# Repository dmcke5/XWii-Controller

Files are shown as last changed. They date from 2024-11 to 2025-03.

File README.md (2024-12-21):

# XWii Controller
An Xbox One style controller with a Wii U layout!

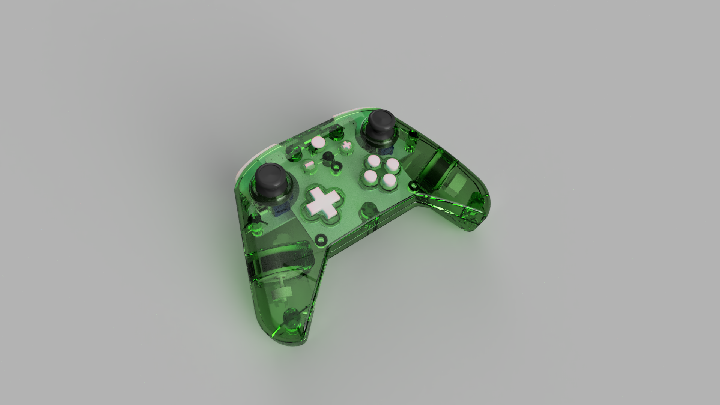
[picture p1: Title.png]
Xii-U Controller


The Wii U gamepad layout is a fan-favourite for many gamers yet it is rarely used in the current generation of controllers. This open source project brings the Wii-U layout back but in a shape more akin to an Xbox controller and provides you with a cool piece of tech that you can be proud to say you built yourself!

Features:
- Wii-U controller layout
- Hall Effect Joysticks
- Hall Effect Triggers
- Rumble
- Xinput Compatible
- RGB Status indicator home button

For now, this controller is wired only but I plan to add a wireless version of the design at some point in the future!

# Print Orientation

If you're printing the housing at home on an FDM printer here's some tips to get the best finish possible!

#### Front Housing

Stand the front housing on its top edge and lean it forward 45 degrees. Enable supports for surfaces over 55 degrees and use a raft to ensure good adhesion to the bed. Ensure Z seam is on the inside! Only minimal supports should be generated, just to support the bottom of the button holes. If you're using a bed-slinger, orient your part so that it runs with the direction your bed moves to reduce wobble.

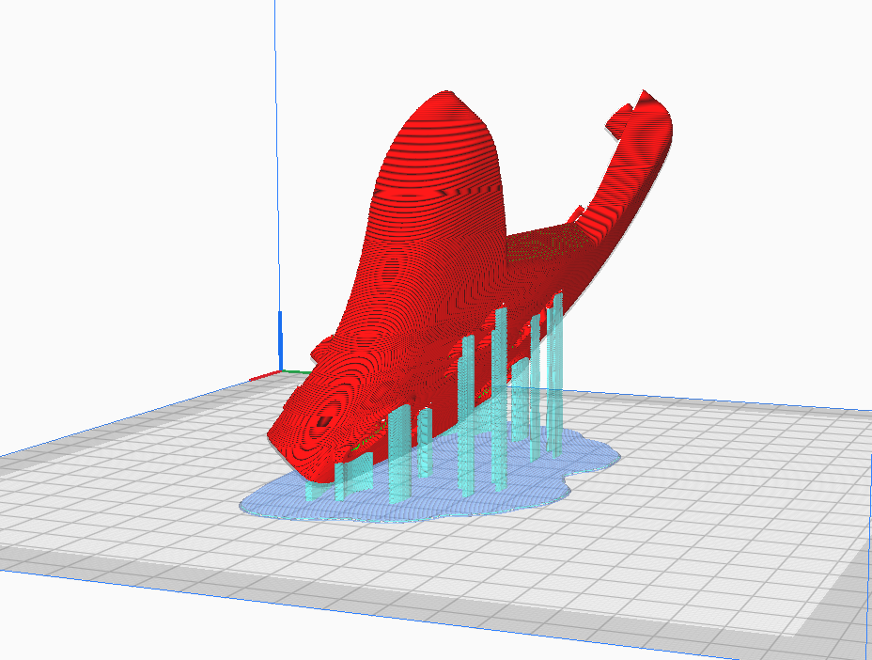
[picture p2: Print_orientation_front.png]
Print orientation front


#### Rear Housing

Stand the rear housing on its top edge and lean it back 30 degrees. Enable supports for surfaces over 55 degrees and use a raft to ensure good adhesion to the bed. Ensure Z seam is on the inside! Some supports will be generated on the inside but none are in contact with critical surfaces making cleanup relatively easy. Same as the front, ensure orientation matches your bed movements for bed slinger printers!

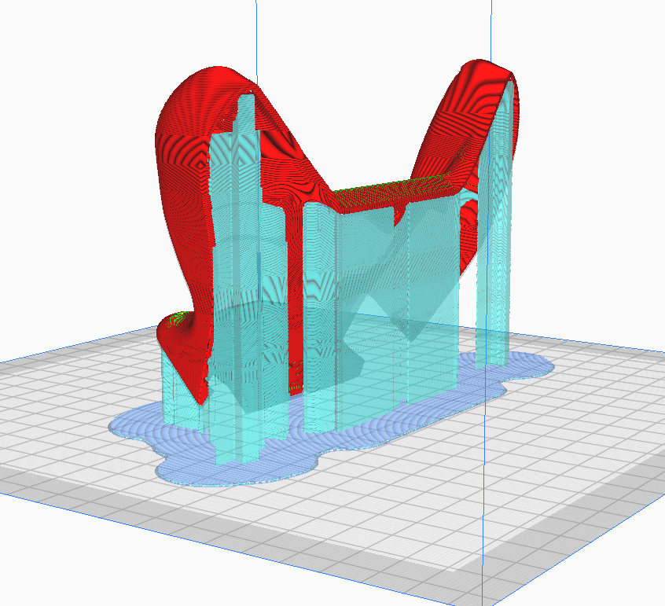
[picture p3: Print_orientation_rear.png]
Print orientation rear


#### Shoulder Buttons

Shoulder buttons should be printed flat on the bed, to ensure the spring is working with the layers rather than against them. Enable supports so the top edge of the buttons aren't left hanging.

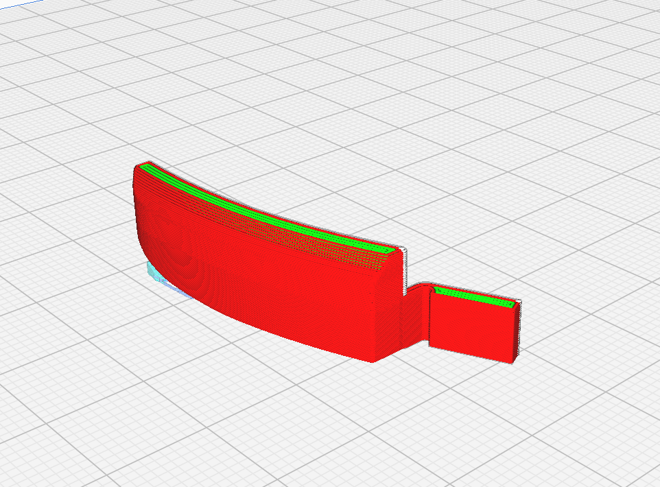
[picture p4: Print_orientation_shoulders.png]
Print orientation shoulders


#### Trigger Buttons

Stand trigger buttons on their end and rotate forward 30 degrees. Enable supports for surfaces over 55 degrees and enable raft. Supports should be generated in the holes and for the magnet mount only leaving very little cleanup required.

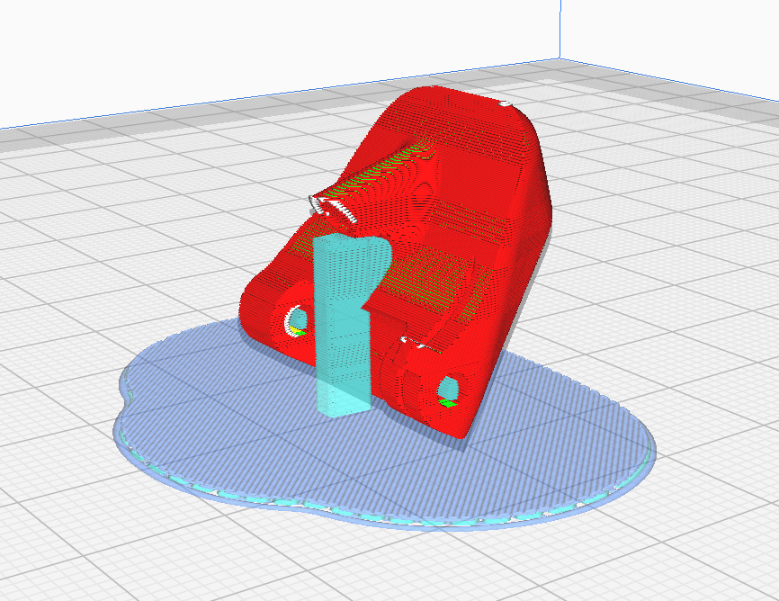
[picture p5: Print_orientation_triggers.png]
Print orientation triggers


# Bill of materials

#### PCB's

1x Front PCB (Must use ENIG finish!)

1x Rear PCB

#### 3D Printing

1x Controller Housing Top

1x Controller Housing Bottom

1x LHS Shoulder Button

1x LHS Trigger

1x RHS Shoulder Button

1x RHS Trigger

#### Purchase

1x Switch lite button set - https://www.aliexpress.com/item/1005007266706005.html

1x Switch lite membrane set - https://www.aliexpress.com/item/1005004544710872.html

2x PS5 Hall sensor joysticks - https://www.aliexpress.com/item/1005007688806322.html

1x Xbox rumble motor (pair) - https://www.aliexpress.com/item/1005002877455453.html

2x PS4/5 Trigger Springs - https://www.aliexpress.com/item/1005005844578554.html

2x 3x1mm Neodymium Magnets - https://www.aliexpress.com/item/1005006619263188.html

1x 6028 RGB LED - https://www.aliexpress.com/item/1005003719602946.html

1x WS2811 IC - https://www.aliexpress.com/item/32844615804.html

1x USB Data Cable (End will be removed so only need to ensure it has the correct end for your device on one end of the cable)

#### Hardware

5x M3x5x5 Threaded Inserts

2x M2x3.2x3 Threaded Inserts

3x M2x3.2x4 Threaded Inserts

5x M3x8 SHCS Screws

6x M2x4 SHCS Screws

# PCB Assembly

#### Front PCB:

Follow the diagram below for locations of components. Pay close attention to orientation of parts U1, Y1, U7 and D1 as they can be fitted in the wrong direction and cause damage. Align marks on all these components with the alignment marks on the PCB.

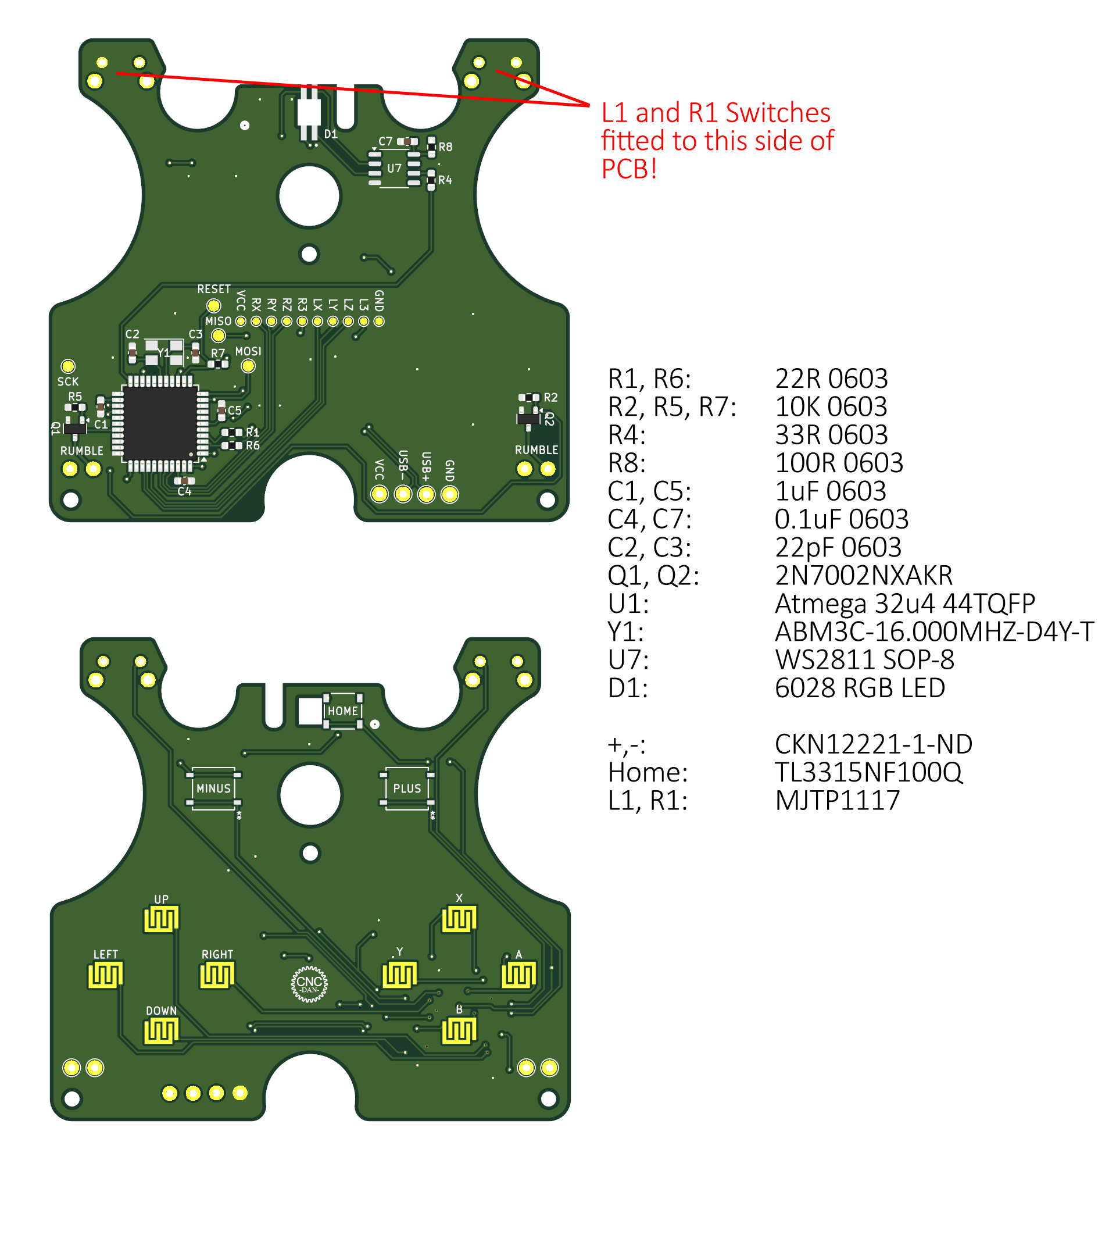
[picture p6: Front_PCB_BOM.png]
Front PCB BOM


#### Rear PCB:

Follow the diagram below for locations of components. Fit joysticks to opposite side of PCB.

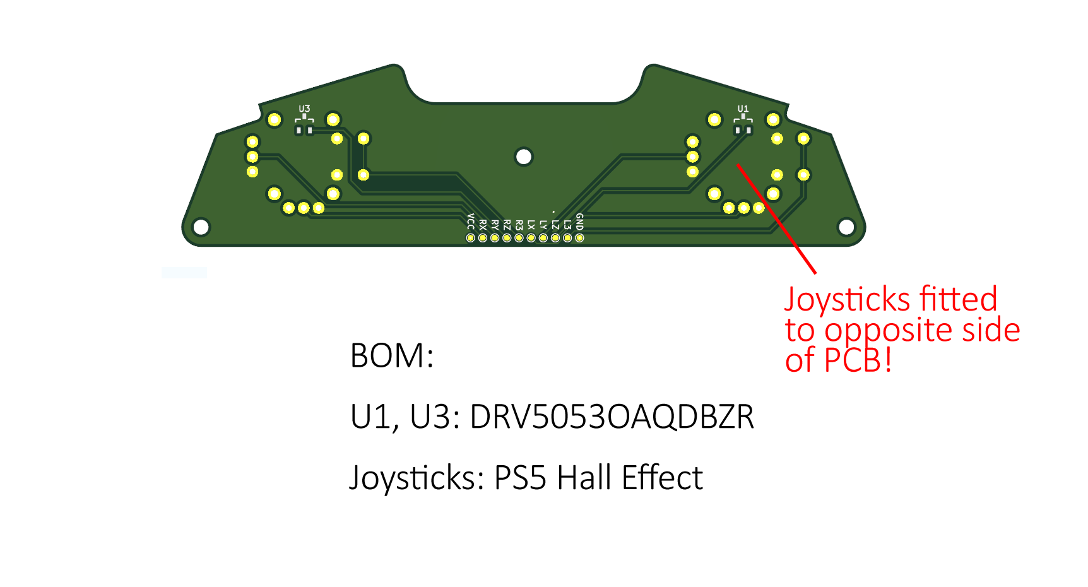
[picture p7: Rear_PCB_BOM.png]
Rear PCB BOM


# Software

You will need to install these libraries to be able to compile the code:

XInput: https://github.com/dmadison/ArduinoXInput

FastLED: https://github.com/FastLED/FastLED

Then simply compile and upload to your controller using the Leonardo w/xinput board option. Please note, once the code is uploaded you will need to re-flash the bootloader to be able to upload code again due to a limitation in the way the xinput library works.

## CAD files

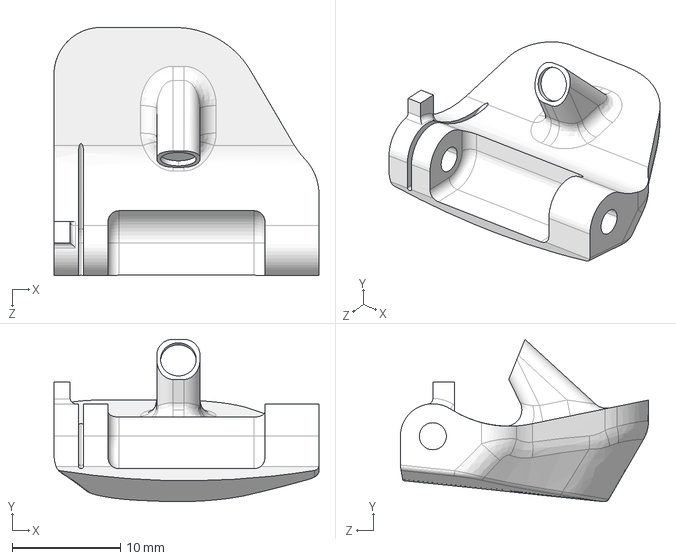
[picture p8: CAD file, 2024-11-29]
3D Files/STEP/RHS Trigger.STEP
24.5 x 15.0 x 23.0 mm

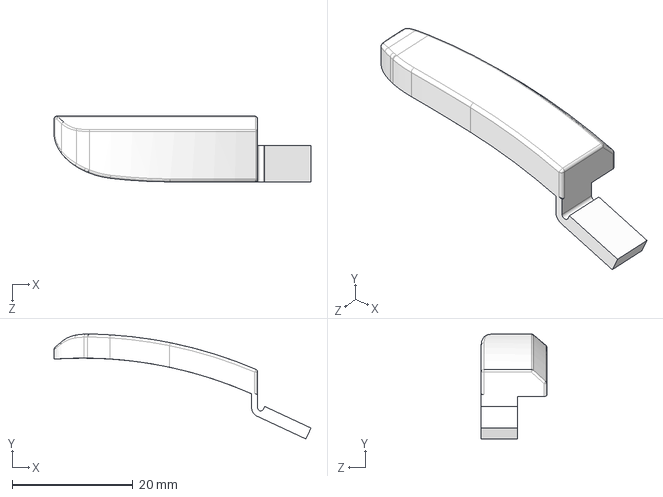
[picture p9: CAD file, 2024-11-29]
3D Files/STEP/LHS Shoulder Button.STEP
42.6 x 17.4 x 10.9 mm

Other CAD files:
3D Files/STEP/LHS Trigger.STEP
3D Files/STEP/RHS Shoulder Button.STEP
3D Files/STL/LHS Shoulder Button.STL
3D Files/STL/LHS Trigger.STL
3D Files/STL/RHS Shoulder Button.STL
3D Files/STL/RHS Trigger.STL

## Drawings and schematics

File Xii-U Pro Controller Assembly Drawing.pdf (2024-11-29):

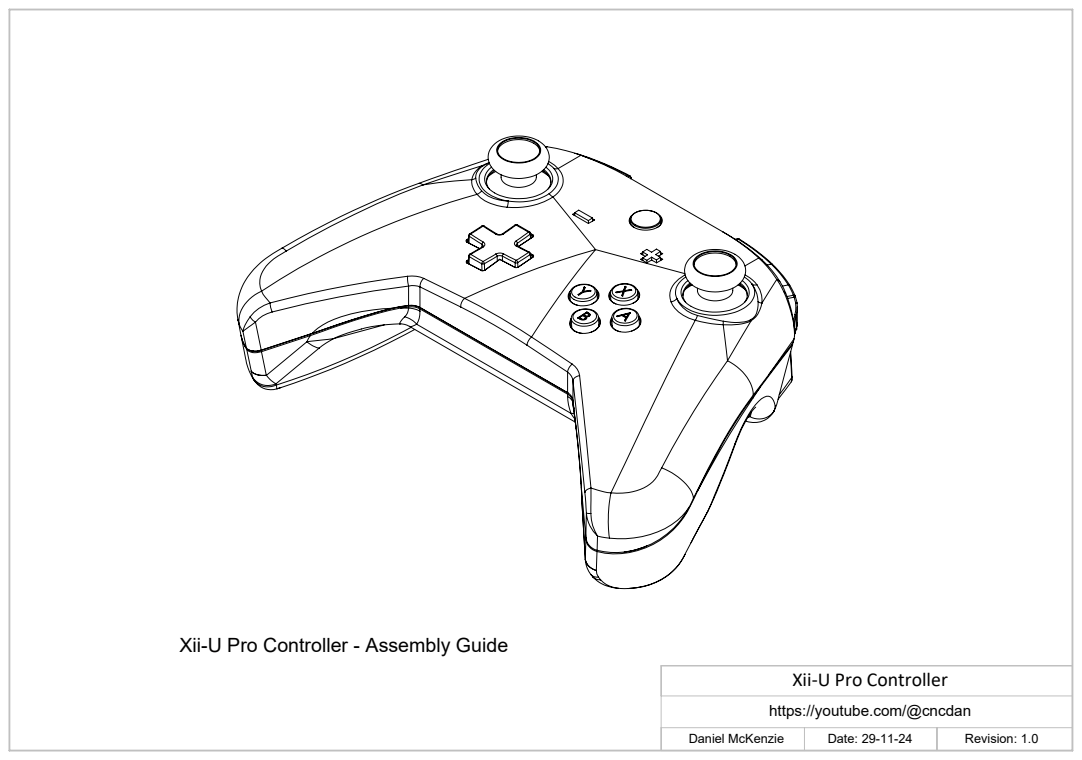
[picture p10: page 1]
Daniel McKenzie; Date: 29-11-24; Revision: 1.0

Xii-U Pro Controller - Assembly Guide

Xii-U Pro Controller
https://youtube.com/@cncdan

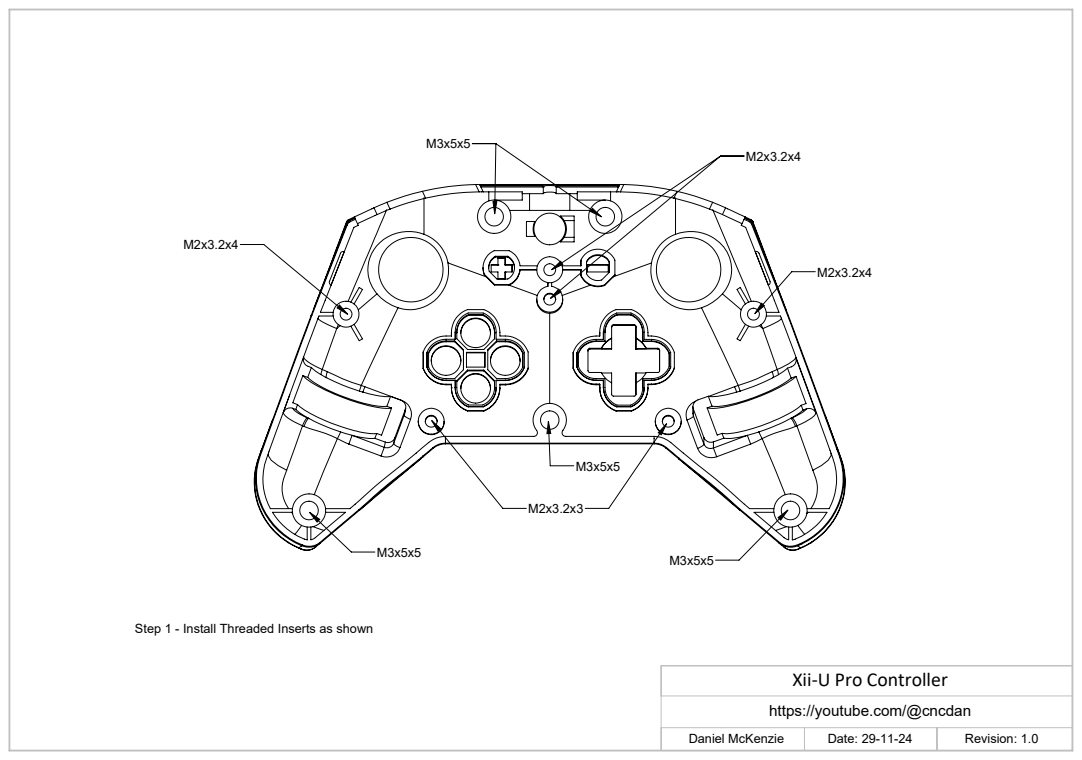
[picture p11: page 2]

Step 1 - Install Threaded Inserts as shown

Xii-U Pro Controller

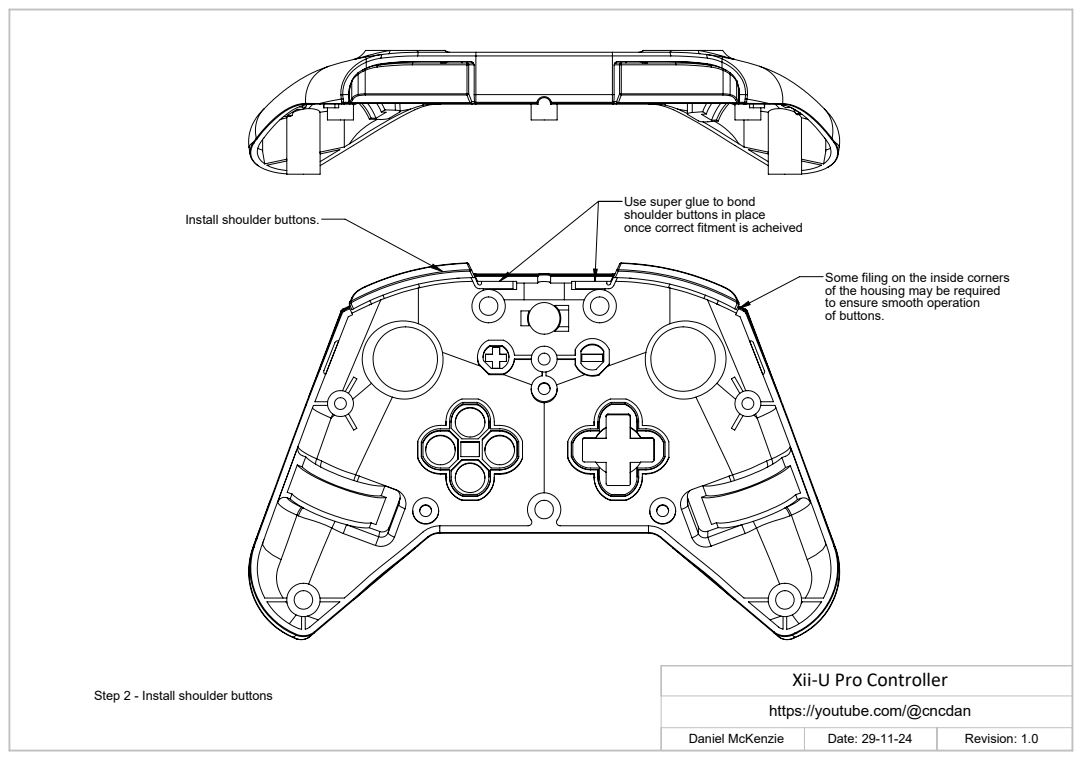
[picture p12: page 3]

Use super glue to bond
shoulder buttons in place
once correct fitment is acheived

Install shoulder buttons.

Some filing on the inside corners
of the housing may be required
to ensure smooth operation
of buttons.

Xii-U Pro Controller

Step 2 - Install shoulder buttons

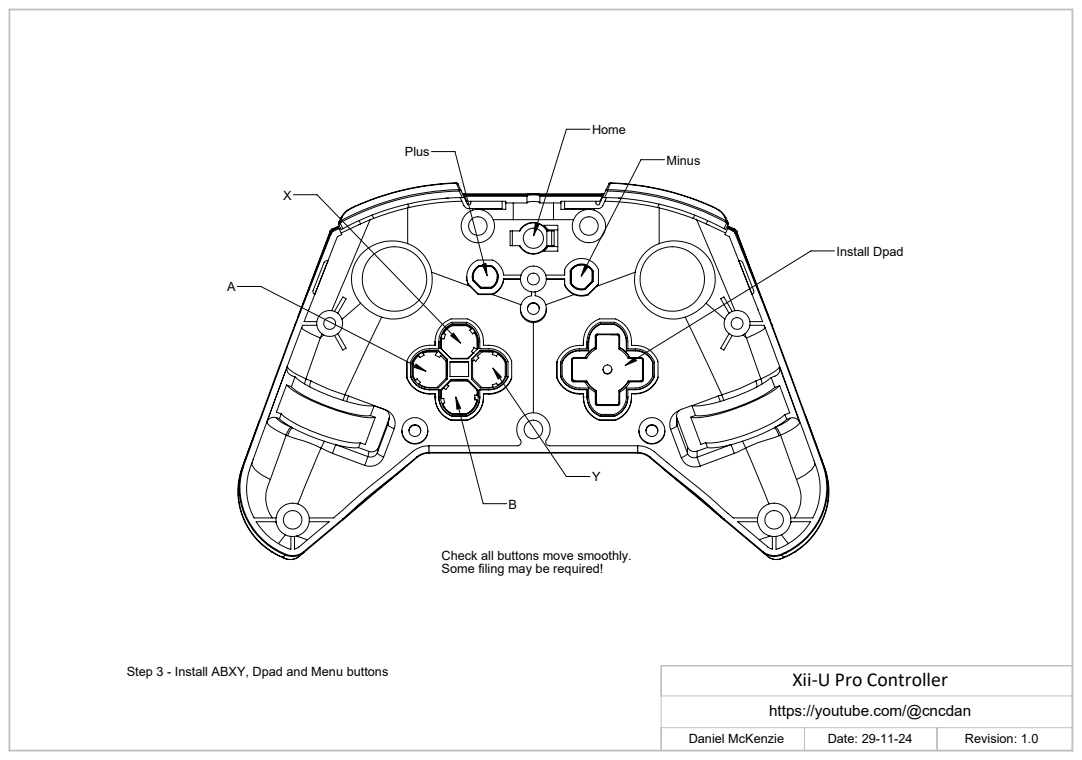
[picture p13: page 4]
Install Dpad; Minus Plus; Step 3 - Install ABXY, Dpad and Menu buttons; Xii-U Pro Controller

Check all buttons move smoothly.
Some filing may be required!

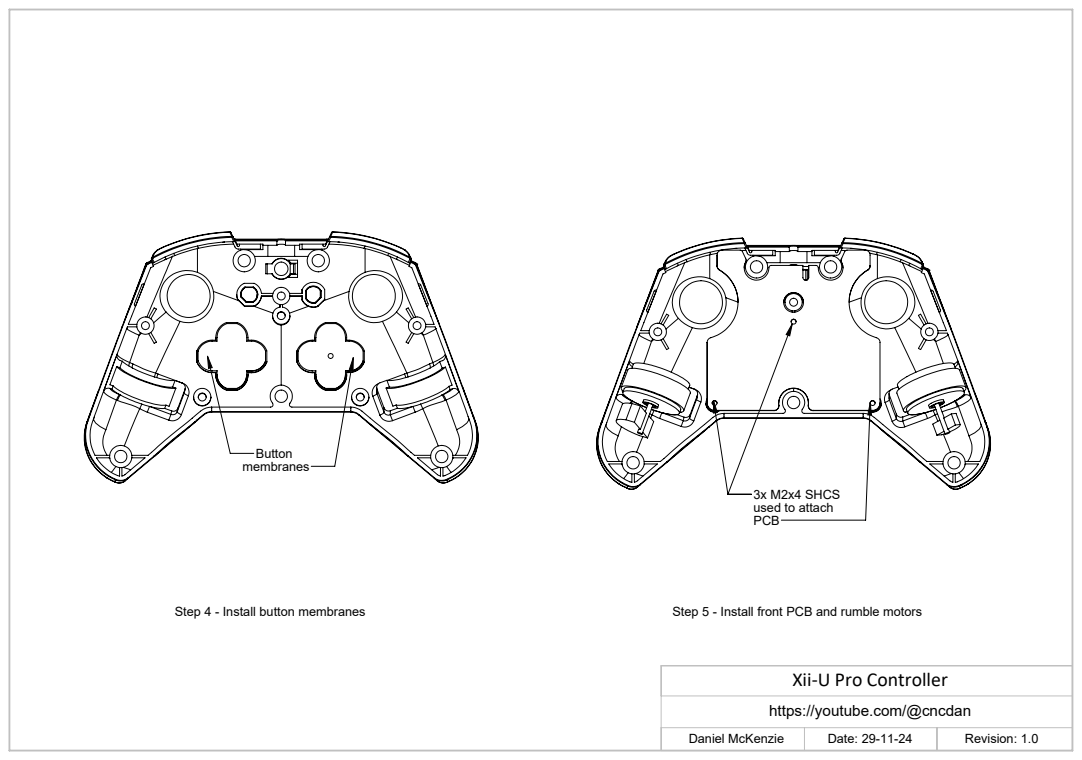
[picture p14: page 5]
Step 4 - Install button membranes; Step 5 - Install front PCB and rumble motors

3x M2x4 SHCS
used to attach
PCB

Xii-U Pro Controller

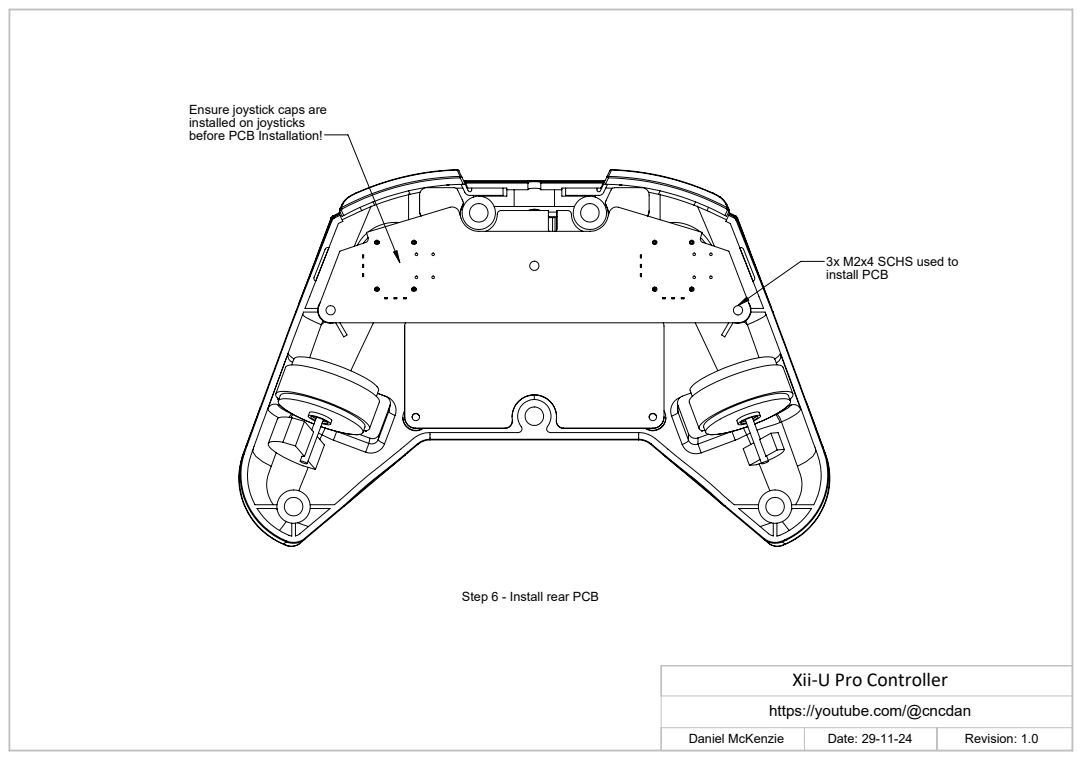
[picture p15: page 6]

Ensure joystick caps are
installed on joysticks
before PCB Installation!

3x M2x4 SCHS used to
install PCB

Step 6 - Install rear PCB

Xii-U Pro Controller

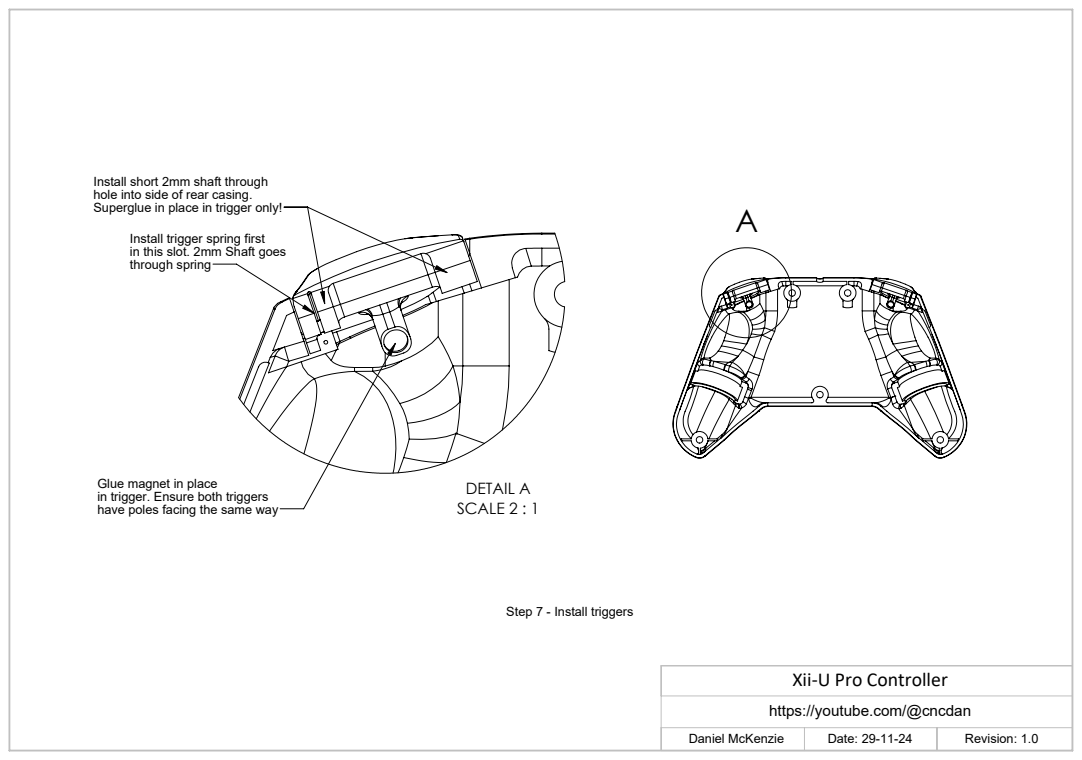
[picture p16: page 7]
DETAIL A SCALE 2 : 1

Install short 2mm shaft through
hole into side of rear casing.
Superglue in place in trigger only!
Install trigger spring first
in this slot. 2mm Shaft goes
through spring

Glue magnet in place
in trigger. Ensure both triggers
have poles facing the same way

Step 7 - Install triggers

Xii-U Pro Controller

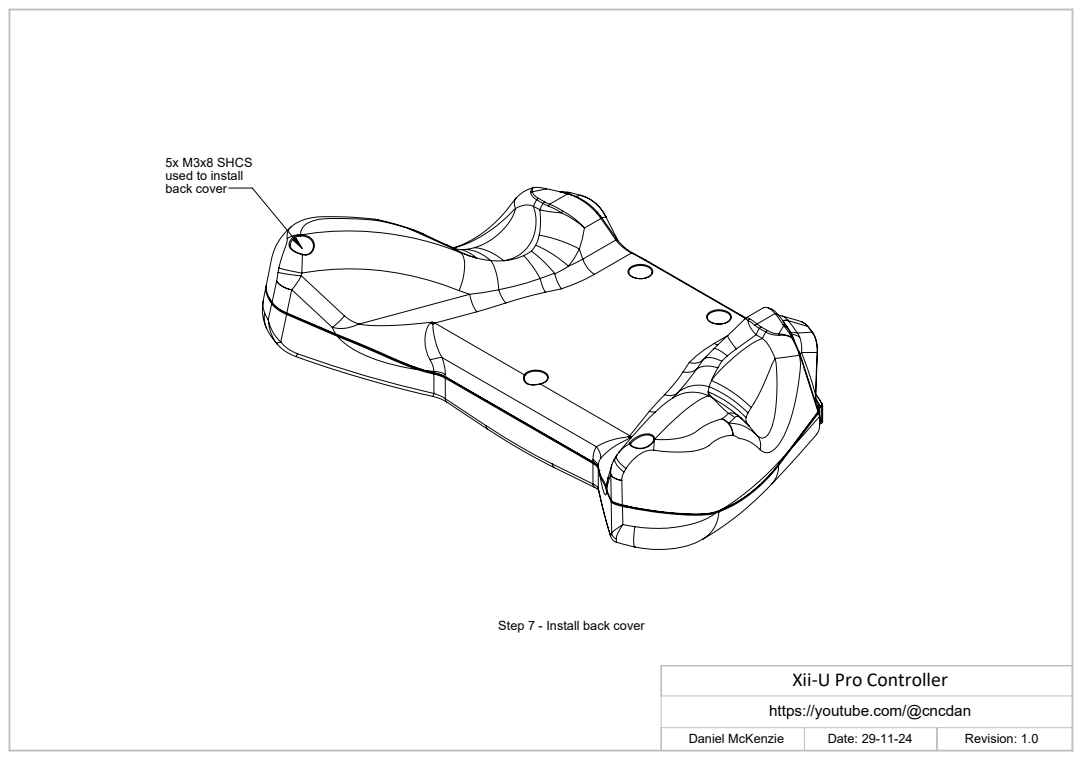
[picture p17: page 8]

5x M3x8 SHCS
used to install
back cover

Step 7 - Install back cover

Xii-U Pro Controller

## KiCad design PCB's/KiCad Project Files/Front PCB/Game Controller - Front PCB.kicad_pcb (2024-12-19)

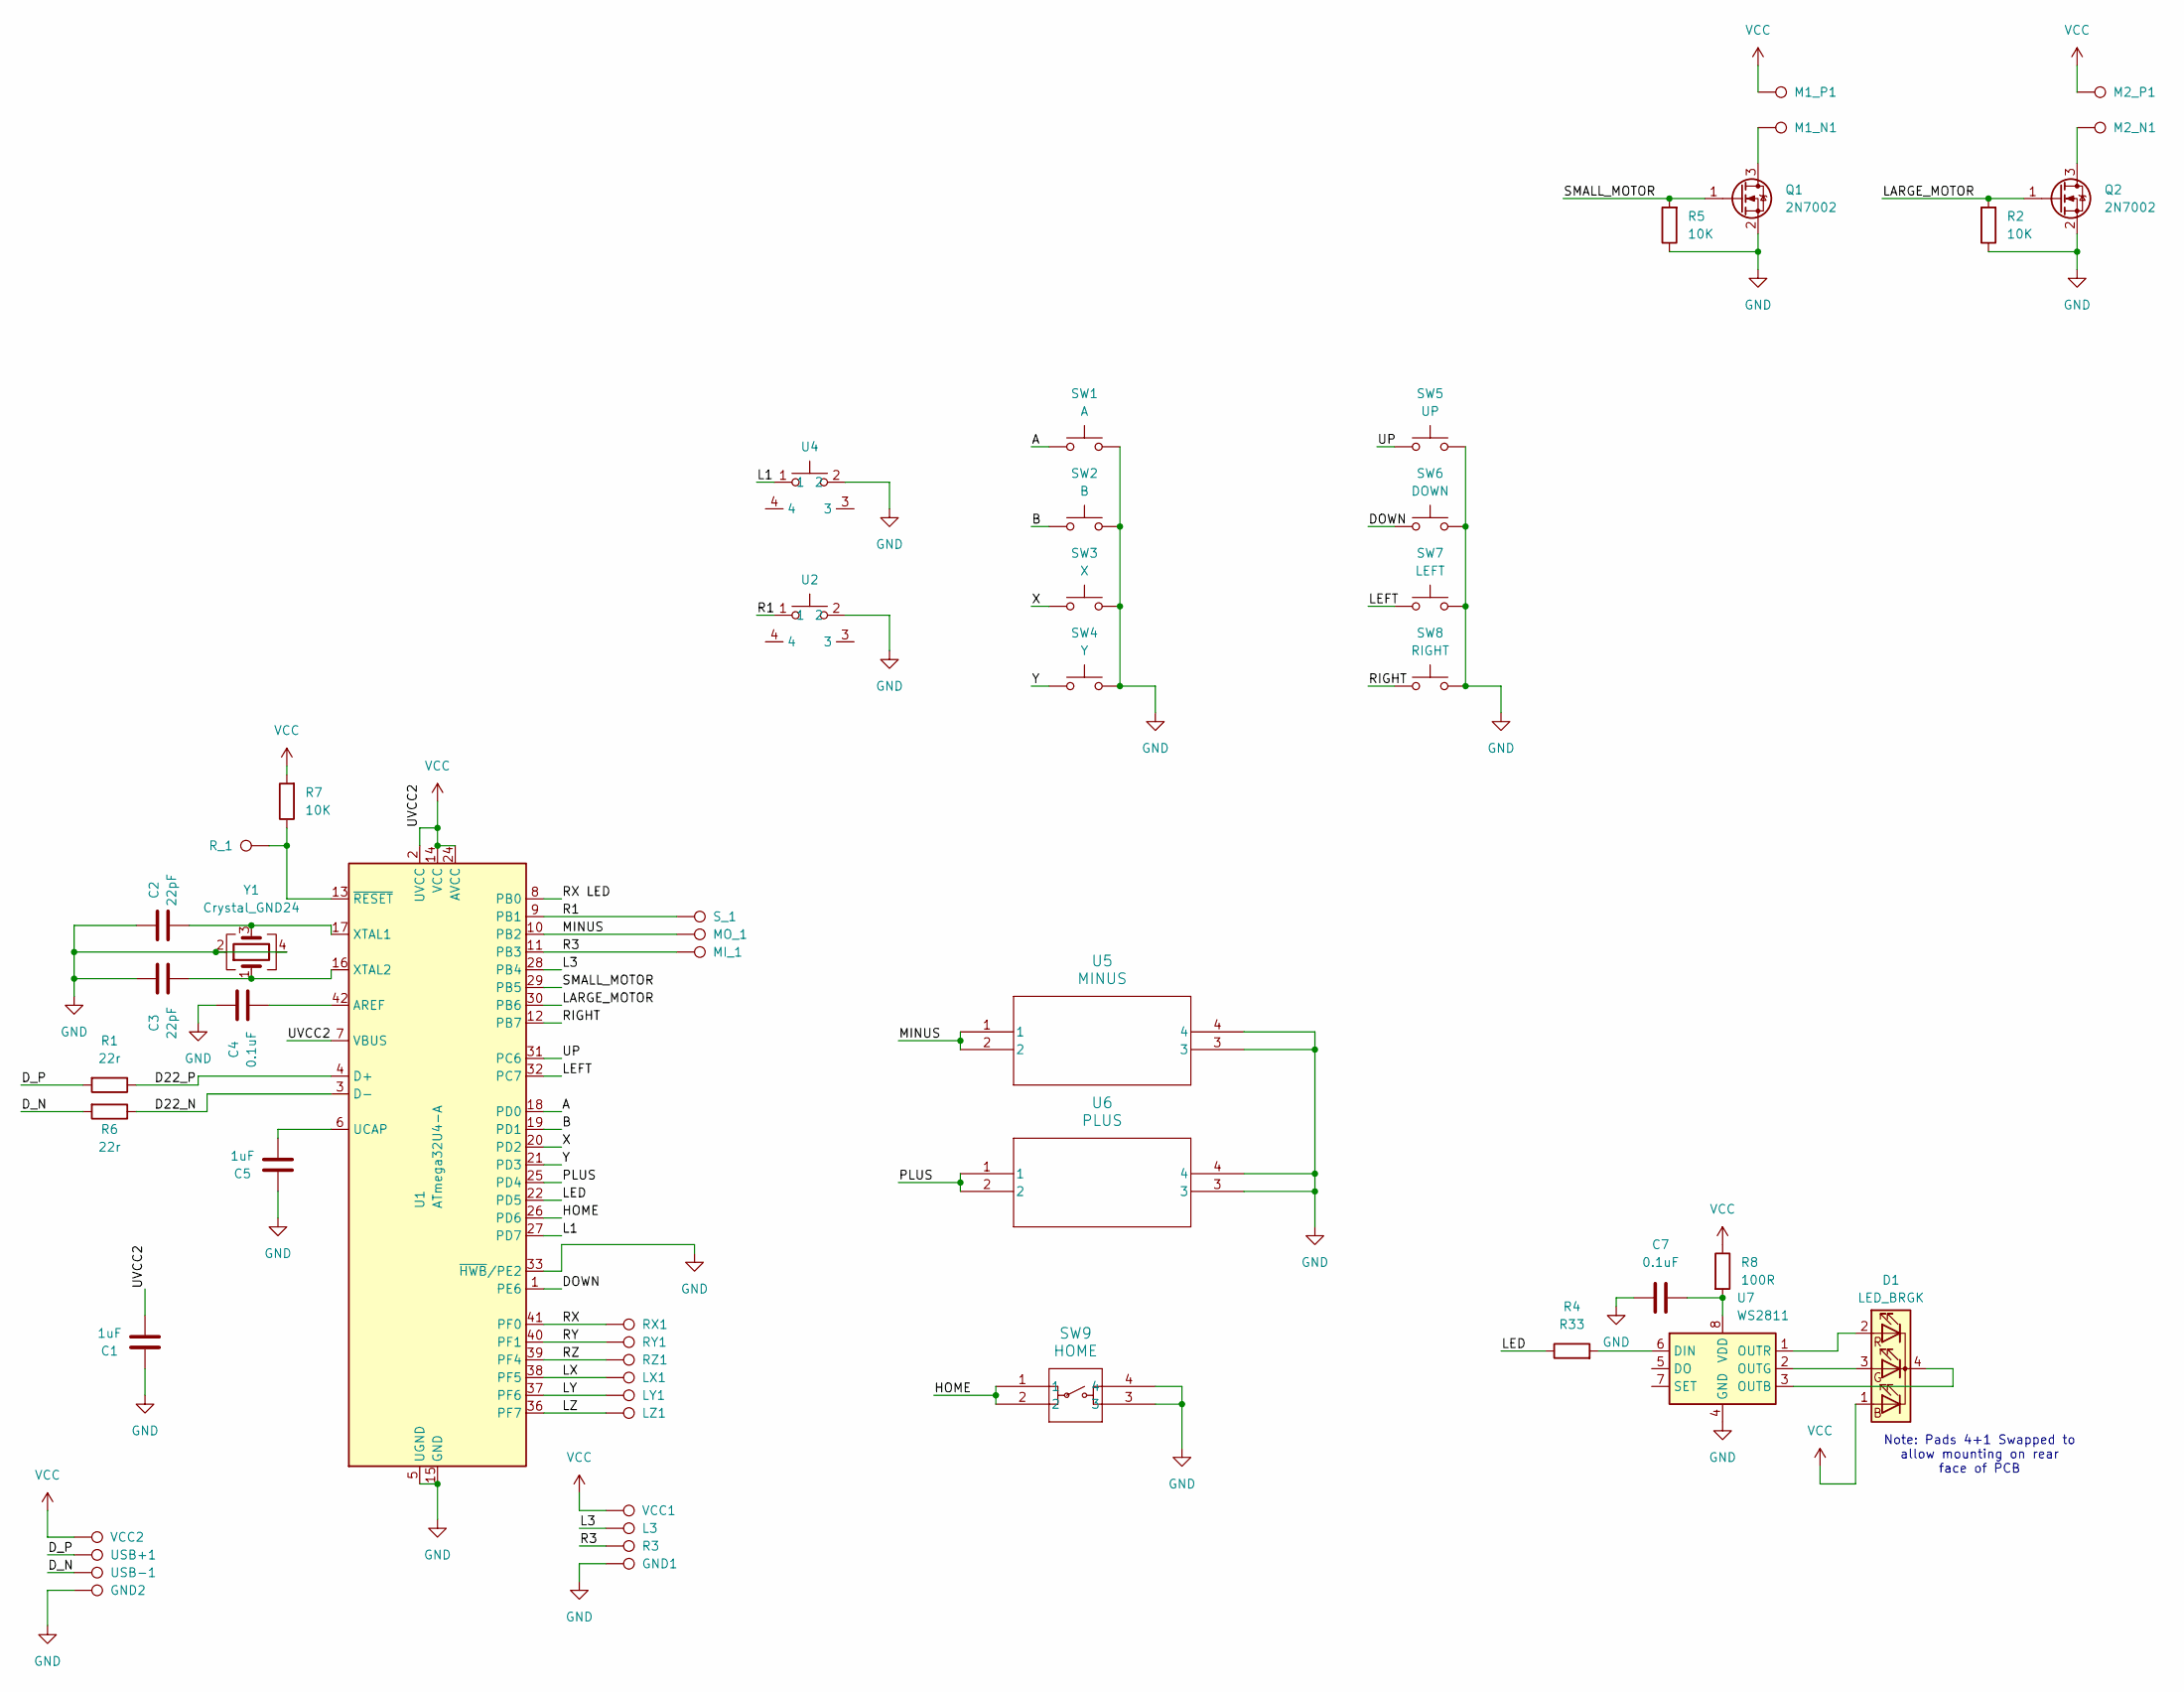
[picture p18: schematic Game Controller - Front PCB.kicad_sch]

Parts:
C1, C5: 1uF; C_0603_1608Metric_Pad1.08x0.95mm_HandSolder
C2, C3: 22pF; C_0603_1608Metric_Pad1.08x0.95mm_HandSolder
C4, C7: 0.1uF; C_0603_1608Metric_Pad1.08x0.95mm_HandSolder
D1: LED_BRGK; LED_T36K3BGR-05D000121U1930
GND1: GND; TestPoint_Pad_D1.0mm
GND2: GND; TestPoint_THTPad_D2.0mm_Drill1.0mm
L3: L3; TestPoint_Pad_D1.0mm
LX1: LX; TestPoint_Pad_D1.0mm
LY1: LY; TestPoint_Pad_D1.0mm
LZ1: LZ; TestPoint_Pad_D1.0mm
M1_N1, M1_P1, M2_N1, M2_P1: MOSI; TestPoint_THTPad_D2.0mm_Drill1.0mm
MI_1: MISO; TestPoint_Pad_D1.5mm
MO_1: MOSI; TestPoint_Pad_D1.5mm
Q1, Q2: 2N7002; SOT-23
R1, R6: 22r; R_0603_1608Metric_Pad0.98x0.95mm_HandSolder
R2, R5, R7: 10K; R_0603_1608Metric_Pad0.98x0.95mm_HandSolder
R3: R3; TestPoint_Pad_D1.0mm
R4: R33; R_0603_1608Metric_Pad0.98x0.95mm_HandSolder
R8: 100R; R_0603_1608Metric_Pad0.98x0.95mm_HandSolder
RX1: RX; TestPoint_Pad_D1.0mm
RY1: RY; TestPoint_Pad_D1.0mm
RZ1: RZ; TestPoint_Pad_D1.0mm
R_1: RESET; TestPoint_Pad_D1.5mm
SW1: A; Membrane Button Small
SW2: B; Membrane Button Small
SW3: X; Membrane Button Small
SW4: Y; Membrane Button Small
SW5: UP; Membrane Button Small
SW6: DOWN; Membrane Button Small
SW7: LEFT; Membrane Button Small
SW8: RIGHT; Membrane Button Small
SW9: HOME; TL3315NF100Q_EWI
S_1: SCK; TestPoint_Pad_D1.5mm
U1: ATmega32U4-A; TQFP-44_10x10mm_P0.8mm
U2, U4: MJTP1117
U5: MINUS; SMT_FS
U6: PLUS; SMT_FS
U7: WS2811; SOP-8_3.9x4.9mm_P1.27mm
USB+1: USB+; TestPoint_THTPad_D2.0mm_Drill1.0mm
USB-1: USB-; TestPoint_THTPad_D2.0mm_Drill1.0mm
VCC1: VCC; TestPoint_Pad_D1.0mm
VCC2: VCC; TestPoint_THTPad_D2.0mm_Drill1.0mm
Y1: Crystal_GND24; Crystal_SMD_5032-4Pin_5.0x3.2mm

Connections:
/A: SW1.1, U1.18 (PD0)
/B: SW2.1, U1.19 (PD1)
/D22_N: R6.1, U1.3 (D-)
/D22_P: R1.1, U1.4 (D+)
/DOWN: SW6.1, U1.1 (PE6)
/D_N: R6.2, USB-1.1
/D_P: R1.2, USB+1.1
/HOME: SW9.1, SW9.2, U1.26 (PD6)
/L1: U1.27 (PD7), U4.1
/L3: L3.1, U1.28 (PB4)
/LARGE_MOTOR: Q2.1 (G), R2.2, U1.30 (PB6)
/LED: R4.1, U1.22 (PD5)
/LEFT: SW7.1, U1.32 (PC7)
/LX: LX1.1, U1.38 (PF5)
/LY: LY1.1, U1.37 (PF6)
/LZ: LZ1.1, U1.36 (PF7)
/MINUS: MO_1.1, U1.10 (PB2), U5.1, U5.2
/PLUS: U1.25 (PD4), U6.1, U6.2
/R1: S_1.1, U1.9 (PB1), U2.1
/R3: MI_1.1, R3.1, U1.11 (PB3)
/RIGHT: SW8.1, U1.12 (PB7)
/RX: RX1.1, U1.41 (PF0)
/RX LED: U1.8 (PB0)
/RY: RY1.1, U1.40 (PF1)
/RZ: RZ1.1, U1.39 (PF4)
/SMALL_MOTOR: Q1.1 (G), R5.2, U1.29 (PB5)
/UP: SW5.1, U1.31 (PC6)
/X: SW3.1, U1.20 (PD2)
/Y: SW4.1, U1.21 (PD3)
GND: C1.1, C2.1, C3.1, C4.1, C5.1, C7.1, GND1.1, GND2.1, Q1.2 (S), Q2.2 (S), R2.1, R5.1, SW1.2, SW2.2, SW3.2, SW4.2, SW5.2, SW6.2, SW7.2, SW8.2, SW9.3, SW9.4, U1.5 (UGND), U1.15 (GND), U1.23 (GND), U1.33 (~HWB/PE2), U1.35 (GND), U1.43 (GND), U2.2, U4.2, U5.3, U5.4, U6.3, U6.4, U7.4 (GND), Y1.2, Y1.4
unnamed: D1.3 (GA), U7.2 (OUTG)
unnamed: D1.4 (K), U7.3 (OUTB)
unnamed: D1.2 (RA), U7.1 (OUTR)
unnamed: M1_N1.1, Q1.3 (D)
unnamed: M2_N1.1, Q2.3 (D)
unnamed: C4.2, U1.42 (AREF)
unnamed: C5.2, U1.6 (UCAP)
unnamed: C2.2, U1.17 (XTAL1), Y1.3
unnamed: C3.2, U1.16 (XTAL2), Y1.1
unnamed: R7.1, R_1.1, U1.13 (~RESET)
unnamed: R4.2, U7.6 (DIN)
unnamed: C7.2, R8.2, U7.8 (VDD)
VCC: C1.2, D1.1 (BA), M1_P1.1, M2_P1.1, R7.2, R8.1, U1.2 (UVCC), U1.7 (VBUS), U1.14 (VCC), U1.24 (AVCC), U1.34 (VCC), U1.44 (AVCC), VCC1.1, VCC2.1

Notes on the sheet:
Note: Pads 4+1 Swapped to allow mounting on rear face of PCB

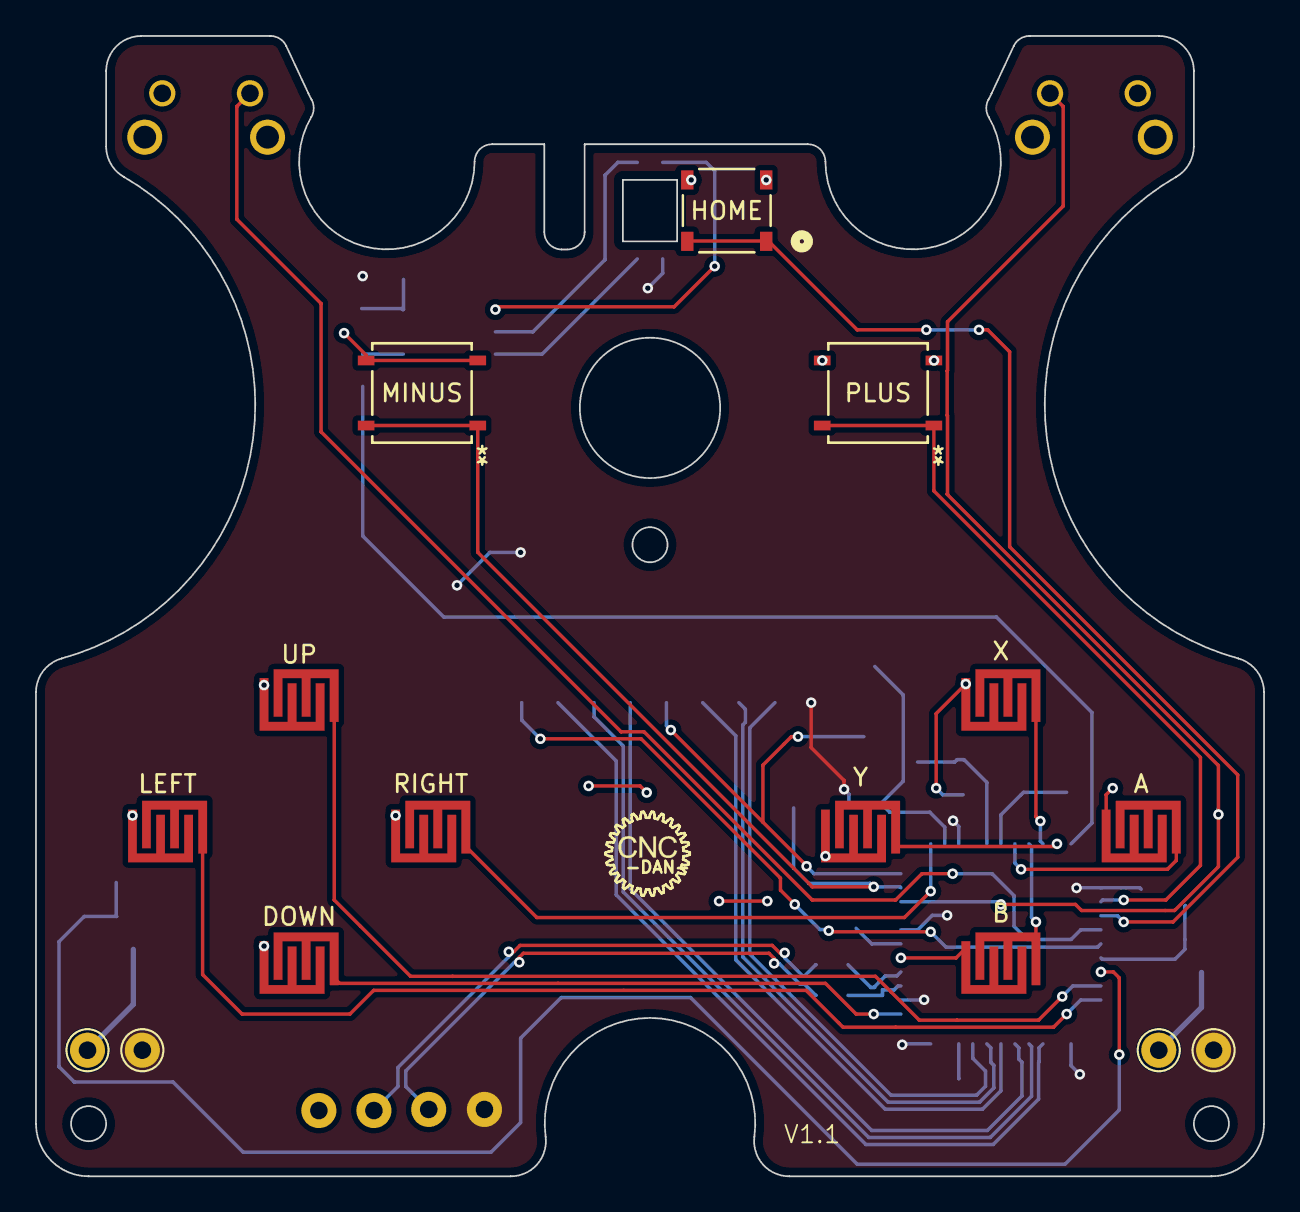
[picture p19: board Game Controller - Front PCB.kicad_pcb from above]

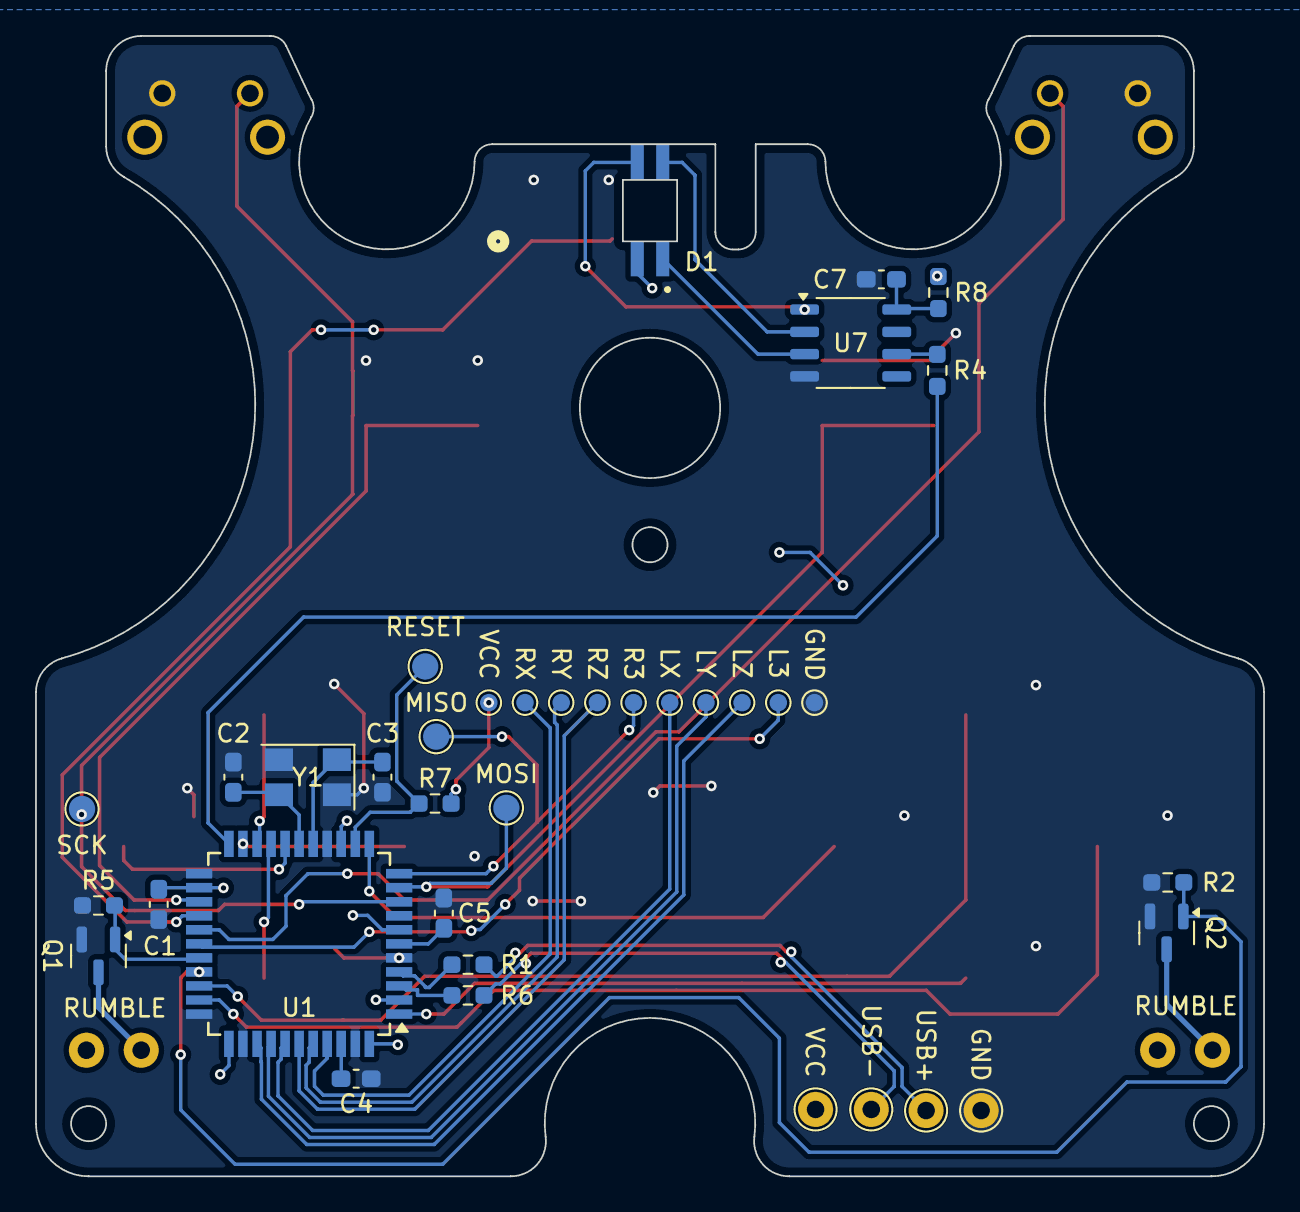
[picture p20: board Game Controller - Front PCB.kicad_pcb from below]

Board: 2 copper layers, 70.0 x 65.0 mm, 54 parts (38 on the bottom side), 42 nets.

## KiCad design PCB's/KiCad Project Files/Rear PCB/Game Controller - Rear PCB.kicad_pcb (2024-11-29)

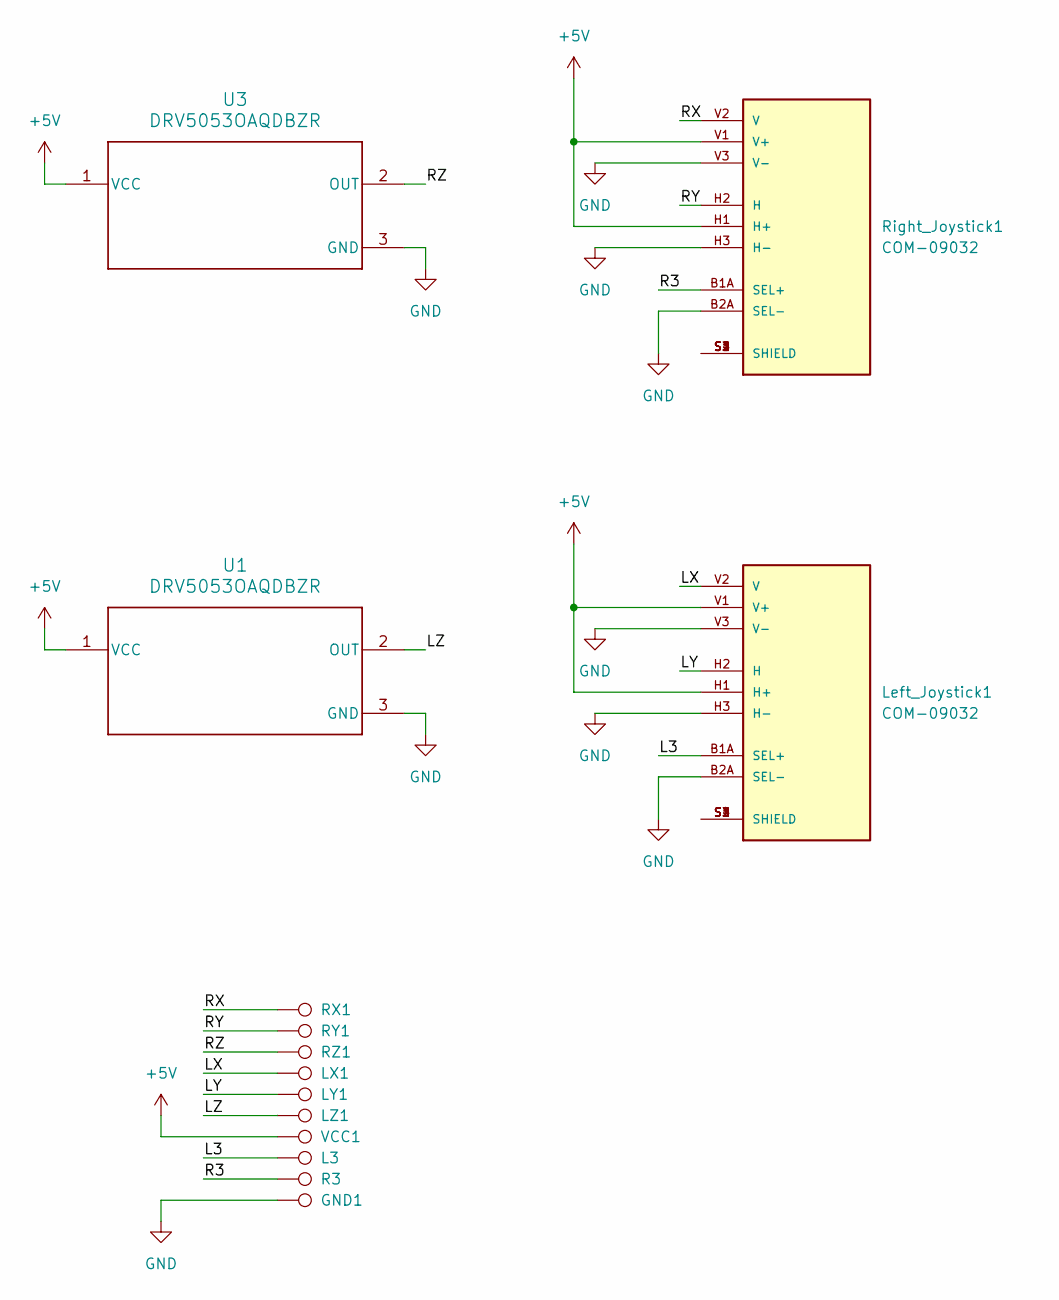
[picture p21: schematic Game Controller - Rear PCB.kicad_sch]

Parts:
GND1: GND; TestPoint_Pad_D1.0mm
L3: L3; TestPoint_Pad_D1.0mm
LX1: LX; TestPoint_Pad_D1.0mm
LY1: LY; TestPoint_Pad_D1.0mm
LZ1: LZ; TestPoint_Pad_D1.0mm
Left_Joystick1: COM-09032; PS5 Joystick; PARTREV N/A
R3: R3; TestPoint_Pad_D1.0mm
RX1: RX; TestPoint_Pad_D1.0mm
RY1: RY; TestPoint_Pad_D1.0mm
RZ1: RZ; TestPoint_Pad_D1.0mm
Right_Joystick1: COM-09032; PS5 Joystick; PARTREV N/A
U1, U3: DRV5053OAQDBZR; DBZ0003A_N
VCC1: VCC; TestPoint_Pad_D1.0mm

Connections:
+5V: Left_Joystick1.H1 (H+), Left_Joystick1.V1 (V+), Right_Joystick1.H1 (H+), Right_Joystick1.V1 (V+), U1.1 (VCC), U3.1 (VCC), VCC1.1
/L3: L3.1, Left_Joystick1.B1A (SEL+)
/LX: LX1.1, Left_Joystick1.V2 (V)
/LY: LY1.1, Left_Joystick1.H2 (H)
/LZ: LZ1.1, U1.2 (OUT)
/R3: R3.1, Right_Joystick1.B1A (SEL+)
/RX: RX1.1, Right_Joystick1.V2 (V)
/RY: RY1.1, Right_Joystick1.H2 (H)
/RZ: RZ1.1, U3.2 (OUT)
GND: GND1.1, Left_Joystick1.B2A (SEL-), Left_Joystick1.H3 (H-), Left_Joystick1.V3 (V-), Right_Joystick1.B2A (SEL-), Right_Joystick1.H3 (H-), Right_Joystick1.V3 (V-), U1.3 (GND), U3.3 (GND)
unnamed: Left_Joystick1.S1 (SHIELD), Left_Joystick1.S2 (SHIELD), Left_Joystick1.S3 (SHIELD), Left_Joystick1.S4 (SHIELD)
unnamed: Right_Joystick1.S1 (SHIELD), Right_Joystick1.S2 (SHIELD), Right_Joystick1.S3 (SHIELD), Right_Joystick1.S4 (SHIELD)

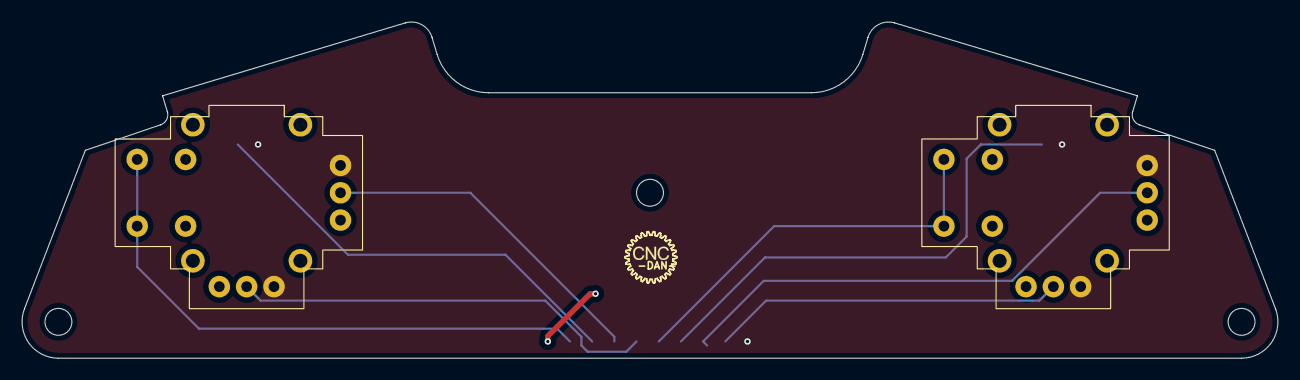
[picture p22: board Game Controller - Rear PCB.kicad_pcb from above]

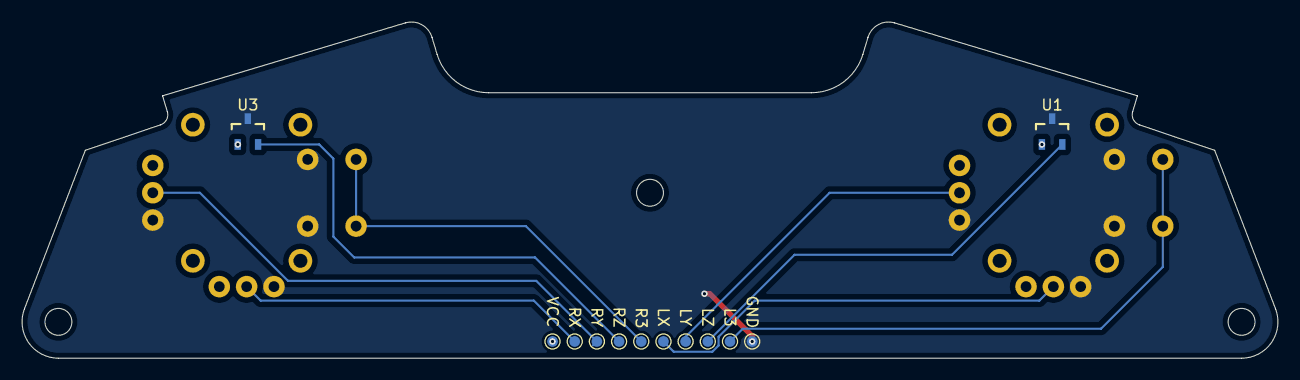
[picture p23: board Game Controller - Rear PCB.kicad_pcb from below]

Board: 2 copper layers, 116.8 x 31.3 mm, 14 parts (12 on the bottom side), 12 nets.

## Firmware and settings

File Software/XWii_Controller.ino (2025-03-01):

#include <EEPROM.h>
#include <XInput.h>
#include <FastLED.h>

#define NUM_LEDS 1
#define DATA_PIN LED_BUILTIN_TX

CRGB leds[NUM_LEDS];
XInputLEDPattern ledPattern;
uint8_t playerNo;
int ledState = 2;
unsigned long ledTimer;

#define PWM62k   1   //62500 Hz
#define PWM8k    2   // 7812 Hz
#define PWM1k    3   //  976 Hz

#define PWM9   OCR1A
#define PWM10  OCR1B
#define PWM11  OCR1C

//Default Joystick calibration settings and EEPROM storage Address
int minLeftX = 0; //EEPROM Adr = 1
int maxLeftX = 720; //EEPROM Adr = 3
int midLeftX = 360; //EEPROM Adr = 5

int minLeftY = 0; //EEPROM Adr = 7
int maxLeftY = 600; //EEPROM Adr = 9
int midLeftY = 390; //EEPROM Adr = 11

int minRightY = 0; //EEPROM Adr = 13
int maxRightY = 760; //EEPROM Adr = 15
int midRightY = 400; //EEPROM Adr = 17

int minRightX = 0; //EEPROM Adr = 19
int maxRightX = 760; //EEPROM Adr = 21
int midRightX = 390; //EEPROM Adr = 23

int minL2 = 10;  //EEPROM Adr = 25
int maxL2 = 230;  //EEPROM Adr = 27
int minR2 = 10;  //EEPROM Adr = 29
int maxR2 = 230; //EEPROM Adr = 31

//Joystick LookUp Tables, compiled at startup or after joystick calibration.
byte leftXLUT[400];
byte leftYLUT[400];
byte rightXLUT[400];
byte rightYLUT[400];

float scaleFactor;    //-----------------------------
int scaleMax = 255;   //Used for LUT calculations
int lutLength = 400;  //-----------------------------

//Joystick Settings
const bool invertLeftY = true;        //------------------------------------------
const bool invertLeftX = false;       //Change these settings for Inverted mounting 
const bool invertRightY = false;      //of joysticks.
const bool invertRightX = false;      //------------------------------------------
int invertLeftZ = 0;             //Set automatically during calibration. Stored: EEPROM Adr = 33
int invertRightZ = 0;            //Set automatically during calibration. Stored: EEPROM Adr = 35
const int deadBand = 10;              //Joystick deadband settings. 
const bool useDeadband = true;        //
const int earlyStop = 30;             //Distance from end of travel to achieve full axis movement.
const int triggerDeadband = 5;       //Trigger Deadband

boolean calibrationMode = false;  //Set to true to open Calibration menu
int calibrationStep = 1;          //Stage of calibration process
int leftZNeutral;                 //Used during calibration process to record trigger neutral position
int rightZNeutral;                //and correct for reversed magnet orientation.

//Controller IO setup
int buttonCount = 15;                   //Number of buttons connected
byte buttonPins[15] = {15,16, 14, 8, 11, 5, 13, 3, 2, 0, 1, 4, 12, 6, 7}; //R1, Minus, R3, L3, Right, Up, Left, A, B, X, Y, Plus, Home, L1, Down,  

#define leftZ A0
#define leftX A2
#define leftY A1
#define rightZ A3
#define rightX A5
#define rightY A4

byte smallMotor = 9; 
byte largeMotor = 10; 

//Button state arrays
byte lastButtonState[15]; //Empty State array for buttons last sent state.
byte currentButtonState[15]; //Empty State array for buttons.

//Current rumble values
uint8_t rumbleLeft = 0;
uint8_t rumbleRight = 0;

void setup() {
  Serial.begin(9600);

  FastLED.addLeds<WS2811, DATA_PIN, GRB>(leds, NUM_LEDS);

  XInput.setAutoSend(false);  // Wait for all controls before sending
  XInput.begin();
  XInput.setReceiveCallback(xInputCallback);

  while(!Serial);

  for(int i = 0; i < buttonCount; i++){ //Set all button pins as input pullup. Change to INPUT if using external resistors.
    pinMode(buttonPins[i], INPUT_PULLUP);
  }
  pinMode(leftZ, INPUT); //Set input for left trigger
  pinMode(leftX, INPUT); //Set input for left joystick X
  pinMode(leftY, INPUT); //Set input for left joystick Y
  pinMode(rightZ, INPUT); //Set input for right trigger
  pinMode(rightX, INPUT); //Set input for right joystick X
  pinMode(rightY, INPUT); //Set input for right joystick Y

  pinMode(smallMotor, OUTPUT);
  pinMode(largeMotor, OUTPUT);

  //Configure Fast PWM For Rumble Motors
  pwm91011configure(PWM1k);
  pwmSet9(0);
  pwmSet10(0);
  

  eepromLoad();
  
  buildLUTs();
  XInput.setJoystickRange(0, scaleMax);

  playerNo = XInput.getPlayer();
}

void loop() {
  buttonRead();
  if(calibrationMode){
    joystickCalibration();
    if(ledTimer + 1000 < millis()){
      if(ledState == 0){
        ledState = 1;
        leds[0] = CRGB::Blue;
      } else {
        ledState = 0;
        leds[0] = CRGB::Black;
      }
      ledTimer = millis();
      FastLED.show();
    }
  } else {
    gamepadMode();
  }
  if(lastButtonState[1] == 1 & lastButtonState[11] == 1 & lastButtonState[2] == 1){ //Minus, Plus, R3
    calibrationMode = true;
  }
  if(ledState == 2){
    leds[0] = CRGB::Blue;
    FastLED.show();
    ledState = 0;
  }
}

void gamepadMode(){ //Controller Gamepad mode
  joystickInput();
  //Buttons
  for(int i = 0; i < buttonCount; i++){
    if(lastButtonState[i] != currentButtonState[i]){
      currentButtonState[i] = lastButtonState[i];
    }
  }
  if(rumbleRight > 0){
    //analogWrite(smallMotor, rumbleRight);
    PWM9 = rumbleRight;
  } else {
    PWM9 = 0;
    //digitalWrite(smallMotor, 0);
  }
  if(rumbleLeft > 0){
    PWM10 = rumbleLeft;
  } else {
    PWM10 = 0;
  }

  XInput.setButton(BUTTON_A, lastButtonState[7]);
	XInput.setButton(BUTTON_B, lastButtonState[8]);
	XInput.setButton(BUTTON_X, lastButtonState[9]);
	XInput.setButton(BUTTON_Y, lastButtonState[10]);

	XInput.setButton(BUTTON_LB, lastButtonState[13]);
	XInput.setButton(BUTTON_RB, lastButtonState[0]);

	XInput.setButton(BUTTON_BACK, lastButtonState[1]);
	XInput.setButton(BUTTON_START, lastButtonState[11]);
  XInput.setButton(BUTTON_LOGO, lastButtonState[12]);

	XInput.setButton(BUTTON_L3, lastButtonState[3]);
	XInput.setButton(BUTTON_R3, lastButtonState[2]);

  XInput.setDpad(lastButtonState[5], lastButtonState[14], lastButtonState[6], lastButtonState[4]);
  XInput.send();
}

void joystickInput(){ //Read joysticks and compare to LUT's . Read triggers and scale output
  int var = analogRead(leftY) / (float)scaleFactor;
  XInput.setJoystickY(JOY_LEFT, leftYLUT[var]);

  var = analogRead(leftX) / (float)scaleFactor;
  XInput.setJoystickX(JOY_LEFT, leftXLUT[var]);
  
  var = analogRead(rightY) / (float)scaleFactor;
  if(var != 0){
    XInput.setJoystickY(JOY_RIGHT, rightYLUT[var]);
  }
  
  var = analogRead(rightX) / (float)scaleFactor;
  if(var != 0){
    XInput.setJoystickX(JOY_RIGHT, rightXLUT[var]);
  }

  var = analogRead(rightZ);
  if(invertRightZ){
    if(var < maxR2 - triggerDeadband){ //Skip scaling and just output minimum if trigger isn't pressed to save time
      var = triggerScale(var, minR2, maxR2, invertRightZ);
      XInput.setTrigger(TRIGGER_RIGHT, var);
    } else {
      XInput.setTrigger(TRIGGER_RIGHT, 0);
    }
  } else {
    if(var > minR2 + triggerDeadband){ //Skip scaling and just output minimum if trigger isn't pressed to save time
      var = triggerScale(var, minR2, maxR2, invertRightZ);
      XInput.setTrigger(TRIGGER_RIGHT, var);
    } else {
      XInput.setTrigger(TRIGGER_RIGHT, 0);
    }
  }

  var = analogRead(leftZ);
  if(invertLeftZ){
    if(var < maxL2 - triggerDeadband){  //Skip scaling and just output minimum if trigger isn't pressed to save time
      var = triggerScale(var, minL2, maxL2, invertLeftZ);
      XInput.setTrigger(TRIGGER_LEFT, var);
    } else {
      XInput.setTrigger(TRIGGER_LEFT, 0);
    }
  } else {
    if(var > minL2 + triggerDeadband){  //Skip scaling and just output minimum if trigger isn't pressed to save time
      var = triggerScale(var, minL2, maxL2, invertLeftZ);
      XInput.setTrigger(TRIGGER_LEFT, var);
    } else {
      XInput.setTrigger(TRIGGER_LEFT, 0);
    }
  }
}

void buttonRead(){ //Read button inputs and set state arrays.
  for (int i = 0; i < buttonCount; i++){
    int input = !digitalRead(buttonPins[i]);
    if (input != lastButtonState[i]){
      lastButtonState[i] = input;
    }
  }
}
//6,4,200,1
int triggerScale(int value, int min, int max, int invert){  //Scales input "value" to 0 - 254 for correct output whilst taking into account deadband.
//int temp;
  if(value > max){
    value = max;
  }
  if(value < min){
    value = min;
  }

  if(!invert){
    return map(value, min, max, 0, 254);
  } else {
    return map(value, max, min, 0, 254);
  }
}

void eepromLoad(){ //Loads stored settings from EEPROM
  if(readIntFromEEPROM(1) != -1){ //Check Joystick Calibration in EEPROM is not Empty
    readCalibrationData(); //Load joystick calibration from EEPROM
  }
}

void writeIntIntoEEPROM(int address, int number){ //Splits int "number" into BYTES and writes to EEPROM at given address
  byte byte1 = number >> 8;
  byte byte2 = number & 0xFF;
  EEPROM.write(address, byte1);
  EEPROM.write(address + 1, byte2);
}

int readIntFromEEPROM(int address){ //Returns int value from EEPROM adress +1
  byte byte1 = EEPROM.read(address);
  byte byte2 = EEPROM.read(address + 1);
  return (byte1 << 8) + byte2;
}

void readCalibrationData(){ //Read calibration data from EEPROM
//Left X
  minLeftX = readIntFromEEPROM(1);
  maxLeftX = readIntFromEEPROM(3);
  midLeftX = readIntFromEEPROM(5);
//Left Y
  minLeftY = readIntFromEEPROM(7);
  maxLeftY = readIntFromEEPROM(9);
  midLeftY = readIntFromEEPROM(11);
//Right Y
  minRightY = readIntFromEEPROM(13);
  maxRightY = readIntFromEEPROM(15);
  midRightY = readIntFromEEPROM(17);
// Right X
  minRightX = readIntFromEEPROM(19);
  maxRightX = readIntFromEEPROM(21);
  midRightX = readIntFromEEPROM(23);
// L2
  minL2 = readIntFromEEPROM(25);
  maxL2 = readIntFromEEPROM(27);
  invertLeftZ = readIntFromEEPROM(33);
// R2
  minR2 = readIntFromEEPROM(29);
  maxR2 = readIntFromEEPROM(31);
  invertRightZ = readIntFromEEPROM(35);
}

void writeCalibrationData(){ //Store calibration data in EEPROM
//Left X
  writeIntIntoEEPROM(1, minLeftX);
  writeIntIntoEEPROM(3, maxLeftX);
  writeIntIntoEEPROM(5, midLeftX);
//Left Y
  writeIntIntoEEPROM(7, minLeftY);
  writeIntIntoEEPROM(9, maxLeftY);
  writeIntIntoEEPROM(11, midLeftY);
//Right Y
  writeIntIntoEEPROM(13, minRightY);
  writeIntIntoEEPROM(15, maxRightY);
  writeIntIntoEEPROM(17, midRightY);
// Right X
  writeIntIntoEEPROM(19, minRightX);
  writeIntIntoEEPROM(21, maxRightX);
  writeIntIntoEEPROM(23, midRightX);
// L2
  writeIntIntoEEPROM(25, minL2);
  writeIntIntoEEPROM(27, maxL2);
  writeIntIntoEEPROM(33, invertLeftZ);
// R2
  writeIntIntoEEPROM(29, minR2);
  writeIntIntoEEPROM(31, maxR2);
  writeIntIntoEEPROM(35, invertRightZ);
}

void lutScaleFactor(){ //Calculates "scale factor" to ensure maximum resolution of LUT's with given memory limitations.
  int largestValue = 0;
  if(maxLeftX > largestValue){
    largestValue = maxLeftX;
  }
  if(maxLeftY > largestValue){
    largestValue = maxLeftY;
  }
  if(maxRightX > largestValue){
    largestValue = maxRightX;
  }
  if(maxRightY > largestValue){
    largestValue = maxRightY;
  }
  scaleFactor = largestValue / (float)lutLength;
}

void buildLUTs(){ //Builds the look up table for each joystick Axis
  lutScaleFactor(); //Calulate Scale Factor for LUT's

  //Left X
  for(int i = 0; i < lutLength; i++){
    leftXLUT[i] = joystickScale(i * scaleFactor, minLeftX, midLeftX, maxLeftX);
  }
  //Left Y
  for(int i = 0; i < lutLength; i++){
    leftYLUT[i] = joystickScale(i * scaleFactor, minLeftY, midLeftY, maxLeftY);
  }
  //Right X
  for(int i = 0; i < lutLength; i++){
    rightXLUT[i] = joystickScale(i * scaleFactor, minRightX, midRightX, maxRightX);
  }
  //Right Y
  for(int i = 0; i < lutLength; i++){
    rightYLUT[i] = joystickScale(i * scaleFactor, minRightY, midRightY, maxRightY);
  }
}

int joystickScale(int value, int min, int mid, int max){
  int output;
  if(value < mid - deadBand){ //Value is less than halfway and outside deadband
    output = map(value, min + earlyStop, mid, 0, scaleMax / 2);
    if(output < 0){
      output = 0;
    }
  } else if(value > mid + deadBand){ //Value is greater than halfway and outside deadband
    output = map(value, mid, max - earlyStop, scaleMax / 2, scaleMax);
    if(output > scaleMax){
      output = scaleMax;
    }
  } else { //Value is within deadband.
    output = scaleMax / 2;
  }
  return output;
}

void joystickCalibration(){ //Joystick Calibration Sequence

  if(calibrationStep == 1){
    buttonRead();
    if(lastButtonState[7] == 1){
      midRightX = analogRead(rightX);
      midRightY = analogRead(rightY);
      midLeftX = analogRead(leftX);
      midLeftY = analogRead(leftY);
      leftZNeutral = analogRead(leftZ);
      rightZNeutral = analogRead(rightZ);
      delay(50);
      minLeftX = midLeftX;
      minLeftY = midLeftY;
      maxLeftX = 0;
      maxLeftY = 0;
      minRightX = midRightX;
      minRightY = midRightY;
      maxRightX = 0;
      maxRightY = 0;
      calibrationStep = 2;
      Serial.println(leftZNeutral);
      PWM9=255;
      delay(100);
      PWM9=0;
      delay(150);
    }
  } else if(calibrationStep == 2){
    int var = analogRead(leftX);
    if(var != 0){
      if(var > maxLeftX) maxLeftX = var;
      if(var < minLeftX) minLeftX = var;
    }
    var = analogRead(leftY);
    if(var != 0){
      if(var > maxLeftY) maxLeftY = var;
      if(var < minLeftY) minLeftY = var;
    }
    var = analogRead(rightX);
    if(var != 0){
      if(var > maxRightX) maxRightX = var;
      if(var < minRightX) minRightX = var;
    }
    var = analogRead(rightY);
    if(var != 0){
      if(var > maxRightY) maxRightY = var;
      if(var < minRightY) minRightY = var;
    }
    buttonRead();
    if(lastButtonState[7] == 1){
      calibrationStep = 3;
      minL2 = 1023;
      maxL2 = 0;
      minR2 = 1023;
      maxR2 = 0;
      PWM9=255;
      delay(100);
      PWM9=0;
      delay(150);
    }
  } else if(calibrationStep == 3){
    int var = analogRead(rightZ);
    if(var != 0){
      if(var > maxR2) maxR2 = var;
      if(var < minR2) minR2 = var;
    }
    var = analogRead(leftZ); //L2
    if(var != 0){
      if(var > maxL2) maxL2 = var;
      if(var < minL2) minL2 = var;
    }
    if(lastButtonState[7] == 1){ //Complete Calibration
    Serial.println(minL2);
    Serial.println(maxL2);
      if(leftZNeutral > minL2){
        invertLeftZ = 1;
        Serial.println("Left Inverted");
      } else {
        invertLeftZ = 0;
      }
      if(rightZNeutral > minR2){
        invertRightZ = 1;
        Serial.println("Right Inverted");
      } else {
        invertRightZ = 0;
      }
      PWM9=255;
      delay(100);
      PWM9=0;
      delay(150);
      writeCalibrationData(); //Update EEPROM
      buildLUTs();
      delay(50);
      calibrationStep = 1;
      calibrationMode = false;
      leds[0] = CRGB::Blue;
      FastLED.show();
    }
  }
}

void xInputCallback(uint8_t packetType) {
	if (packetType == (uint8_t) XInputReceiveType::LEDs) {
		ledPattern = XInput.getLEDPattern();
	}

/*

XInput LED Patterns (currently unused):
  Off = 0x00
	Blinking = 0x01
	Flash1 = 0x02
	Flash2 = 0x03
	Flash3 = 0x04
	Flash4 = 0x05
	On1 = 0x06
	On2 = 0x07
	On3 = 0x08
	On4 = 0x09
	Rotating = 0x0A
	BlinkOnce = 0x0B
	BlinkSlow = 0x0C
	Alternating = 0x0D
  
*/
	else if (packetType == (uint8_t) XInputReceiveType::Rumble) {
		rumbleLeft = XInput.getRumbleLeft();
    rumbleRight = XInput.getRumbleRight();
	}
}

void pwm91011configure(int mode) {
  TCCR1A=1;
  TCCR1B=mode|0x08; 
  TCCR1C=0;
}

void pwmSet9(int value) // Argument is PWM between 0 and 255
{
OCR1A=value;   // Set PWM value
DDRB|=1<<5;    // Set Output Mode B5
TCCR1A|=0x80;  // Activate channel
}

void pwmSet10(int value)  // Argument is PWM between 0 and 255
{
OCR1B=value;   // Set PWM value
DDRB|=1<<6;    // Set Output Mode B6
TCCR1A|=0x20;  // Set PWM value
}

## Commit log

2024-11-29 Add 3D Models
    [LHS Shoulder Button.STEP, LHS Shoulder Button.STL, LHS Trigger.STEP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]
2024-11-29 Added PCB's and Title Image
    [Game Controller - Front PCB.kicad_pcb, Game Controller - Front PCB.kicad_sch, Game Controller - Rear PCB.kicad_pcb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]
2024-11-29 Updates to readme and print orientation suggestions
2024-11-29 Added Assembly Drawing
2024-12-19 Added Front PCB BOM and updated front PCB Gerbers to V1.1
2024-12-19 Added Rear PCB BOM
2024-12-19 Updated front PCB drawing and kicad project files
    [Game Controller - Front PCB.kicad_pcb, Game Controller - Front PCB.kicad_sch]
2024-12-19 Update Controller Housing to suit cheap replacement rumble motors
2024-12-19 Added blank front housing for custom layouts
2024-12-21 Update README.md
    Updated link for rumble motors
2024-12-21 Update README.md
    Updated BOM
2025-01-04 Added automatic detection for inverted magnet orientation during calibration
    [XWii_Controller.ino]
2025-01-04 Added quiet PWM for rumble motors
2025-02-05 Updated Front PCB BOM
    C7 was missing from BOM
2025-03-01 Update XWii_Controller.ino
    Fixed error in rumble code
    [XWii_Controller.ino]
